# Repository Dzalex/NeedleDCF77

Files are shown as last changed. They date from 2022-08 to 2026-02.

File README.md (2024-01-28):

# NeedleDCF77
## General idea
This project is clock that shows time using three analog meters (with needle) for time and one VFD for date. Main time reference is [DCF77](https://en.wikipedia.org/wiki/DCF77) signal attainable in most of Europe.
### Assembled clock
DSC_9274edit

## Hardware
### Alredy decided
  - Main microcontroller is *STM32L051C8T6*
  - Power supply is implemnted around Analog Device's *LTC3558*
  - DCF77 receive module is *EB6180B1COB77K5A1*
  - [VFD](https://en.wikipedia.org/wiki/Vacuum_fluorescent_display), have old one - itron FG95A
    - Driver PT6312
    - Driver for fillament - LM4871 (alternative for LM9022)
    - Inverting regulator - LT1617
  - Analog meters are:
    - Simpson 60 x 60 mm for Hours
    - 85C1-A for Minutes
    - 91C4 for Seconds
  - Enclosure is wooden box from Alie, 20 x 10 x 6 cm
  - Battery: Panasonic 18650B

## Software
### Hardware design
Corelated to Hardware, Shematic and PCB is designed in *KiCad*.

### IDE and language
For developing purpose we will use *STMCubeIDE*, because of it's flexibility, configurability and support. Also it provide easy access to RTOS option. We use C programing language.

### RTOS
To implemet firmware in this projet we use [FreeRTOS](https://www.freertos.org/). Main reasone to use RTOS instead programing barebone firmware is contribution implementation, so people have less chance to influence other people work. Great chance to learn something about tasks, semafors, mesage queues and other useful features of RTOS! :)

### To decide
  - Planing to use python to implement app for generating time and dates to be able to test.

## Geting stared soon
Coming when some starting point is achived

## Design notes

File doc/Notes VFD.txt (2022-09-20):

- PT6312 je VFD kontroler
	Drajver za filament moze biti LM9022, a to je u stvari spinof LM4871

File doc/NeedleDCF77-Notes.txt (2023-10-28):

//**                     NeedleDCF77 Notes                                  **\\
********************************************************************************

I Sch
    1.  Na USB ulazu, nama se desilo da imamo velike nalete struje kada vežemo
        punjač na kolo koje ima dosta kapacitivnosti ili svičere, koji mogu da 
        povuku dosta struje pre nego što kondenzator dođe skroz sebi. Poslednji
        put smo upotrebili NCP330 (lakše pakovanje za tebe je NCP331) i jako smo
        zadovoljni. Ne znam koliko je realno da se spale pinovi USB-a, ali seti
        se Apple kabla za punjenje i crnih pinova na onom malom konektoru. 
        (Čak je i preporučeno na strani 20 DS-a za LT3558)
    2.  Shield može da se spoji na zemlju ali je dobra praksa da se stavi kolo
        kao na slici 1 i 1.1, kako bi se izolovala DC putanja kroz antenu.            
    3.  Slazem se za 5k1 na CCx pinovima. 
    4.  Napajanje za LTC3558 je preporuceno da ima 1 uF, ti si stavio 10 uF ali 
        elko, ne bi bila loša ideja zameniti to sa keramikom i razmisliti o
        postavljanju nekog ferrite bead-a između USB-a i napajanja (LTC pravi
        lep ripple na napajanju kada radi). Mislim takođe da 100 nF na ulazu ne 
        pomaže ništa :') 
        Mnogo lep blog: https://www.murata.com/en-global/products/emc/emifil/library/knowhow/basic/chapter06-p8
        Posebno su mi interesantni feedthru kondenzatori sa tri pina. 
    5.  Za buck su predložili kaleme od 2.2 uH do 10 uH. Ja bih na tvom mestu
        kupio i 10 uH i nešto između 4.7 uH i 10 uH. Može se desiti da će ripple
        praviti problem. Ne znam koliko će struje vući sve kasnije sa njega ali
        brine me pomalo rad u pulse skip modu kada ćeš imati ripple u kHz a ne 
        MHz. Ostavio bih možda mesta i za ferrite bead između 3V0 i MAS6180, kao 
        i mesta za još par kondenzatora (sa strane U3) ukoliko bude potrebno da 
        se dekapluje šum sa napajanja. Vidim da si ostavio na MCU da se brine o 
        režimu rada napajanja, to je dobro. 
        Verujem da si obratio pažnju na struju zasićenja kalema, ne vidim oznaku
        komponente koju si odabrao. Coilcraft i Taiyo Yuden mi se uvek čine kao 
        bezbedan izbor. 
    6.  Crtao si elektrolite na izlazima LTC3558, na strani 24 DS-a piše da se 
        preporučuju MLCC-ovi, da li je to samo do šeme? 
        Otvori dobro oči na derating kapacitvnosti kod MLCC-ova sa radnim 
        naponom jer može lako da bude >-60%!
    7.  Ispravi me ako grešim, prema formuli sa strane 26 DS-a za LTC3558, 
        napon na izlazu je Vout = 0.8 (1 + Vup/Vdn): 
       
            octave:1> 0.8*(1+(820/300))
            ans = 2.9867 # 3 V rail, tačno je. 
       
            octave:2> 0.8*(1+(300/62))
            ans = 4.6710 # 5 V rail, malo podbacuje? 
            Deluje mi kao da bi trebalo da bude 57k2? 
            
    8.  Note 4 DS-a za MAS6180, na strani 6, mi daje ideju da ga možda napajaš 
        samo sa kondenzatora dok se radi hvatanje signala, on troši uA, ako 
        staviš 100 uF do njega i PMOS iznad, možeš kadkad da ga napuniš i onda
        pustiš da radi neko vreme sa svog napajanja. U tom slučaju bi morao da 
        spustiš napon na PDN pinu, možda i da ga vežeš da bude stalno ON a 
        STM neće imati problem sa malim promenama napona na TIME signalu. 
        Još da se nadaš da LTC ne krene da svičuje na 77 kHz i da ne diže common 
        mode noise preko zemlje :'D
    9.  C25 se puni preko Q1, preko čega se prazni? Možda nije loše ubaciti 
        jednu diodu kod njega.
    10. LT1617 je jako fleksibilan sa kalemima, ne znam da li imaš običan ili -1
        ali čini mi se da ako ti bias ne troši puno struje možeš da odeš do 
        gornjih granica induktivnosti. Otpornici mi deluju ispravno odabrani. 
        Pominju na kraju DS cap od 100 pF u paraleli sa tvojim R16, možda 
        ostaviti makar kao NP? 
    11. Sve oko U6 mi deluje skroz oke :) 
    12. U DS za PT6312 piše da je VIH (in high) min 0.7*VDD tj. 3.5 V, kod tebe
        SPI dolazi od MCU koji radi na 3 V, možda si već probao ovo na kod sebe
        ali meni je red flag. 
    13. Hardverski debounce na tasteru je za pi*** :) (Slika 2, proverena šema)
II PCB
    1.  Nije moralo da bude na dva sloja, ali cenim pošten izazov :D 
    2.  Mislim da je layout ispao super u odnosu na ograničenja. Lično ne volim
        da stavljam kalem sa druge strane ploče zato što će kroz vije stalno da 
        piče impulsi i do pola ampera. Možda bih pojačao trejsove oko dva glavna
        kalema na U1, dodao još vija, pojačao stiching poligona mase gde god je
        moguće jer su dosta isprekidane. 
    3.  Trejs za 3V0 svraća na sve čipove dok stigne do najosetljivijeg U3. Tu 
        će svako da doda po još malo šuma i da napravi mnogo padova napona do
        druge ivice ploče. Mislim da na BOT imaš mesta da po dnu provučeš još
        jedan trejs za 3V0 i da to daš samo U3. (Ako pomeriš 5V0, sl. tačka)
    4.  Izgleda mi kao i da 5V0 možeš uz malo masiranja da provučeš uz gornju 
        ivicu ploče do U4 i ostalih ako SWDIO konektor padne ispod J5. 
        Predlog 3 bi ti ukinuo debeli trejs u BOT sloju za 3V0 koji kreće ispod
        MCU i ostavio mesta za manevar. 
    5.  PWM_Fosc se naslonila uz trejs za DCF77_TIME kao da mu treba još šuma :D
    6.  Mršavo mi deluje ovaj trejs za VBUS, vidim da je 0.3 mm ali samo jedna
        vija, možda dve, biće tu struje kada se puni baterija. 
    6.  Ništa mi više ne upada u oči, 3D izgleda lepo!

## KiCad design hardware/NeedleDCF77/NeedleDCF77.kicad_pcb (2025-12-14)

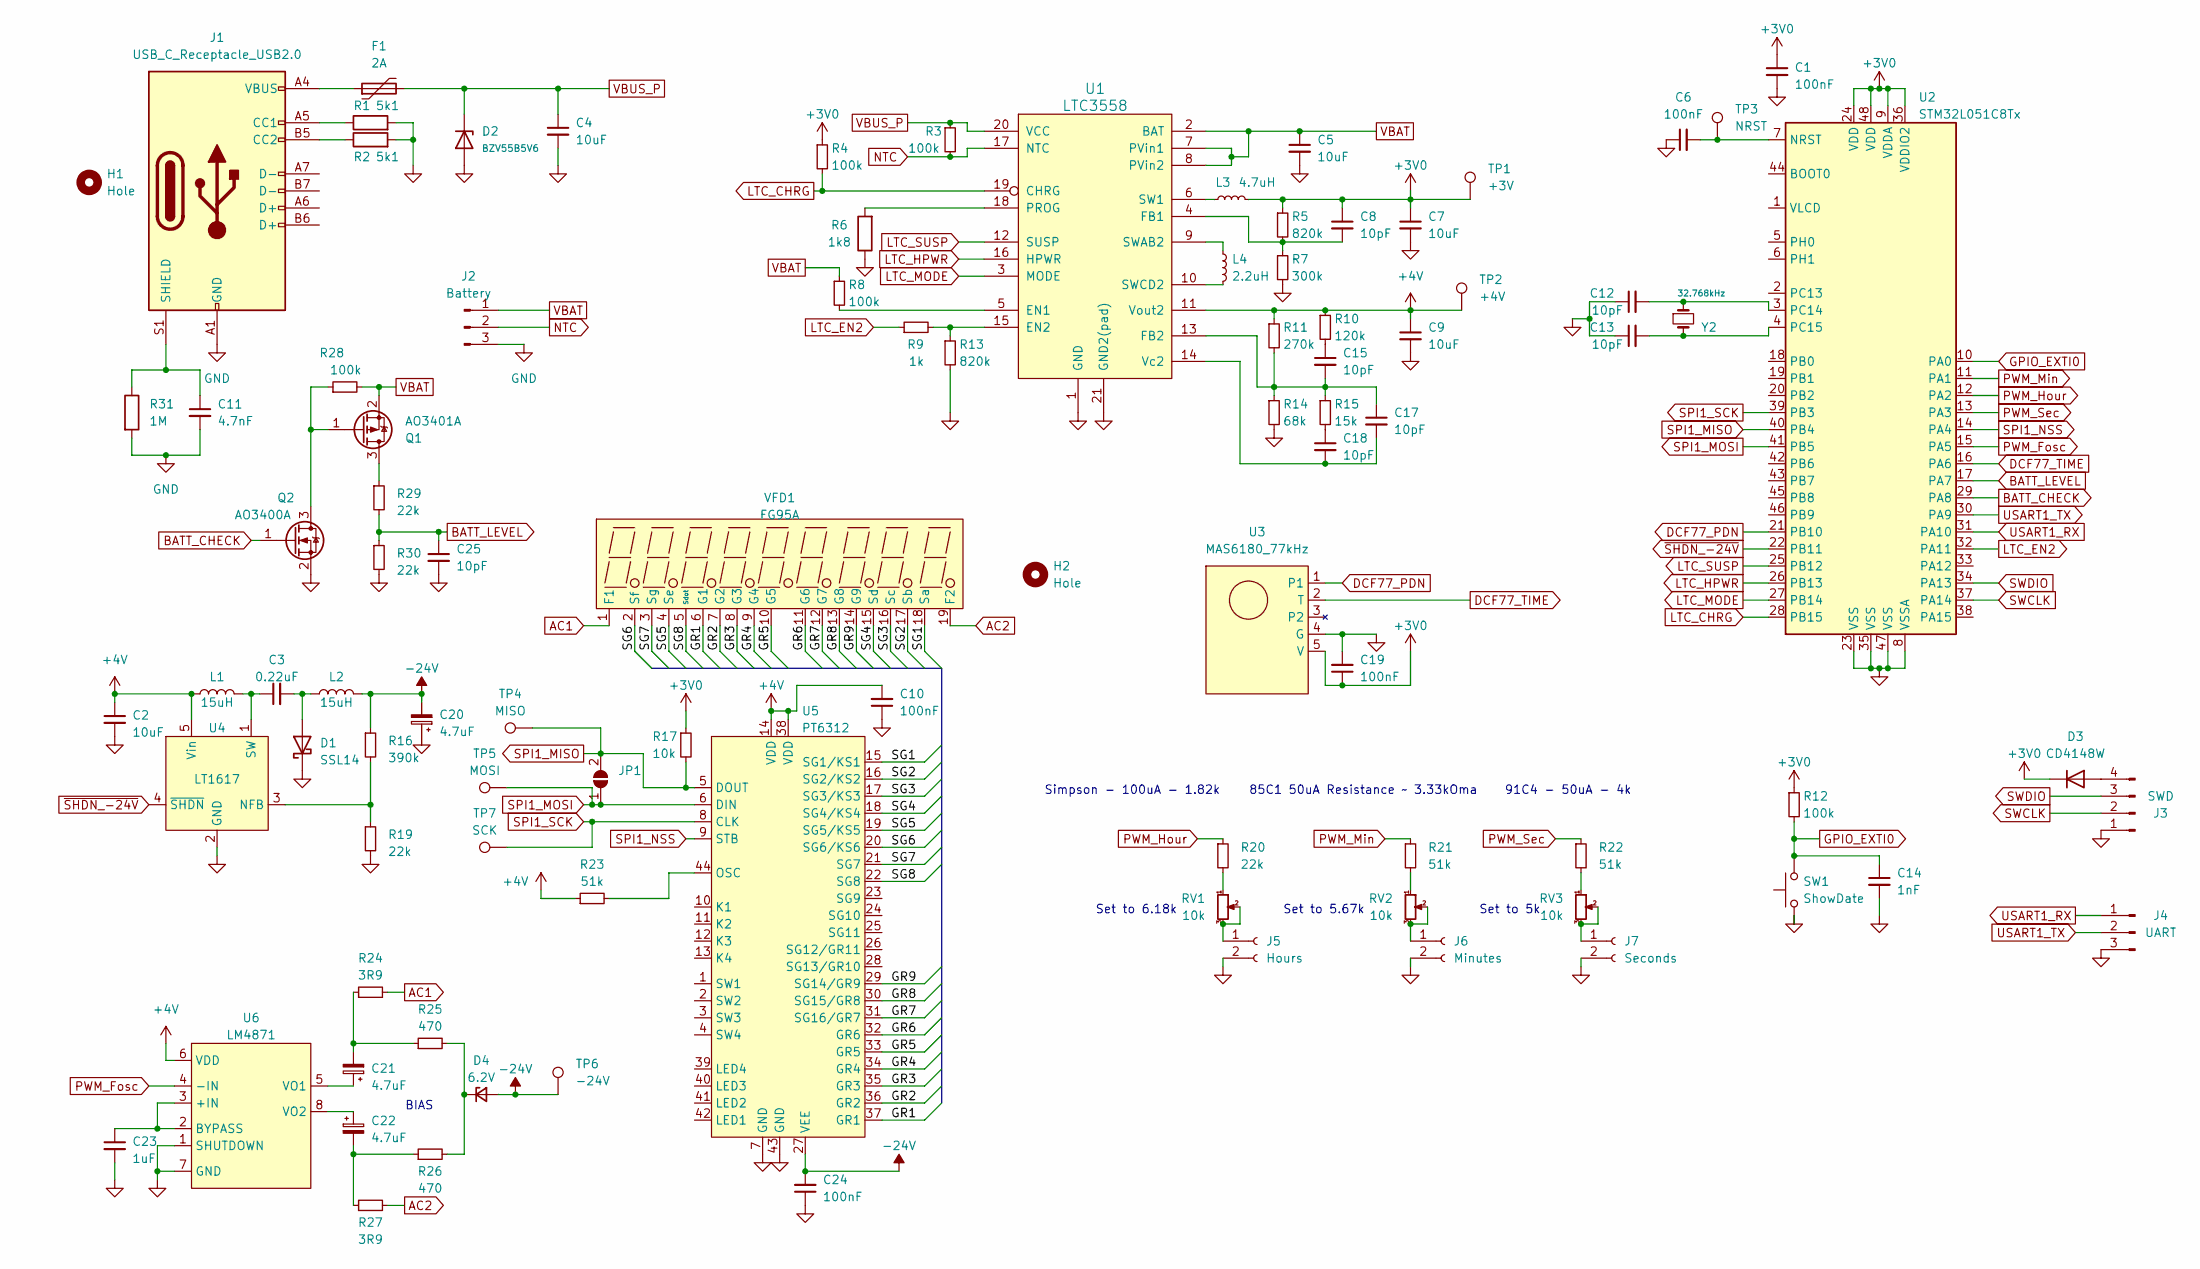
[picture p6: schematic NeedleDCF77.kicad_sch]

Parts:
C1, C6, C10, C19, C24: 100nF; C_0805_2012Metric_Pad1.18x1.45mm_HandSolder
C2, C4, C5, C7, C9: 10uF; C_1206_3216Metric_Pad1.33x1.80mm_HandSolder
C3: 0.22uF; C_1206_3216Metric_Pad1.33x1.80mm_HandSolder
C8, C12, C13, C15, C17, C18, C25: 10pF; C_0805_2012Metric_Pad1.18x1.45mm_HandSolder
C11: 4.7nF; C_1206_3216Metric_Pad1.33x1.80mm_HandSolder
C14: 1nF; C_1206_3216Metric_Pad1.33x1.80mm_HandSolder
C20: 4.7uF; CP_EIA-3528-21_Kemet-B_Pad1.50x2.35mm_HandSolder
C21, C22: 4.7uF; CP_Elec_4x5.7
C23: 1uF; C_0805_2012Metric_Pad1.18x1.45mm_HandSolder
D1: SSL14; D_SMA_Handsoldering
D2: BZV55B5V6; D_MiniMELF
D3: CD4148W; D_0805_2012Metric
D4: 6.2V; D_DO-35_SOD27_P2.54mm_Vertical_AnodeUp
F1: 2A; Fuse_2512_6332Metric_Pad1.52x3.35mm_HandSolder
H1, H2: Hole; MountingHole_3.2mm_M3_DIN965_Pad_TopBottom
J1: USB_C_Receptacle_USB2.0; Molex-2169890001-MFG
J2: Battery; Molex_KK-254_AE-6410-03A_1x03_P2.54mm_Vertical
J3: SWD; PinHeader_1x04_P2.54mm_Vertical
J4: UART; PinHeader_1x03_P2.54mm_Vertical
J5: Hours; Molex_KK-254_AE-6410-02A_1x02_P2.54mm_Vertical
J6: Minutes; Molex_KK-254_AE-6410-02A_1x02_P2.54mm_Vertical
J7: Seconds; Molex_KK-254_AE-6410-02A_1x02_P2.54mm_Vertical
JP1: SolderJumper-2_P1.3mm_Open_TrianglePad1.0x1.5mm
L1, L2: 15uH; L_12x12mm_H8mm
L3: 4.7uH; L_Ferrocore_DLG-0504
L4: 2.2uH; L_Ferrocore_DLG-0504
Q1: AO3401A; SOT-23
Q2: AO3400A; SOT-23
R1, R2: 5k1; R_0805_2012Metric_Pad1.20x1.40mm_HandSolder
R3, R4, R8, R12, R28: 100k; R_0805_2012Metric_Pad1.20x1.40mm_HandSolder
R5, R13: 820k; R_0805_2012Metric_Pad1.20x1.40mm_HandSolder
R6: 1k8; R_0805_2012Metric_Pad1.20x1.40mm_HandSolder
R7: 300k; R_0805_2012Metric_Pad1.20x1.40mm_HandSolder
R9: 1k; R_0805_2012Metric_Pad1.20x1.40mm_HandSolder
R10: 120k; R_1206_3216Metric_Pad1.30x1.75mm_HandSolder
R11: 270k; R_0805_2012Metric_Pad1.20x1.40mm_HandSolder
R14: 68k; R_Axial_DIN0207_L6.3mm_D2.5mm_P2.54mm_Vertical
R15: 15k; R_0805_2012Metric_Pad1.20x1.40mm_HandSolder
R16: 390k; R_0805_2012Metric_Pad1.20x1.40mm_HandSolder
R17: 10k; R_0805_2012Metric_Pad1.20x1.40mm_HandSolder
R19, R20, R29, R30: 22k; R_0805_2012Metric_Pad1.20x1.40mm_HandSolder
R21, R22, R23: 51k; R_0603_1608Metric_Pad0.98x0.95mm_HandSolder
R24, R27: 3R9; R_1206_3216Metric_Pad1.30x1.75mm_HandSolder
R25, R26: 470; R_0805_2012Metric_Pad1.20x1.40mm_HandSolder
R31: 1M; R_0805_2012Metric_Pad1.20x1.40mm_HandSolder
RV1, RV2, RV3: 10k; Potentiometer_Bourns_3296Y_Vertical
SW1: ShowDate; Molex_KK-254_AE-6410-02A_1x02_P2.54mm_Vertical
TP1: +3V; TestPoint_Pad_1.5x1.5mm
TP2: +4V; TestPoint_Pad_1.5x1.5mm
TP3: NRST; TestPoint_Pad_1.5x1.5mm
TP4: MISO; TestPoint_Pad_1.5x1.5mm
TP5: MOSI; TestPoint_Pad_1.5x1.5mm
TP6: -24V; TestPoint_Pad_1.5x1.5mm
TP7: SCK; TestPoint_Pad_1.5x1.5mm
U1: LTC3558; QFN-20-1EP_3x3mm_P0.4mm_EP1.65x1.65mm
U2: STM32L051C8Tx; LQFP-48_7x7mm_P0.5mm
U3: MAS6180_77kHz; MAS6180_module
U4: LT1617; SOT-23-5_HandSoldering
U5: PT6312; LQFP-44_10x10mm_P0.8mm
U6: LM4871; SOIC-8_3.9x4.9mm_P1.27mm
VFD1: FG95A
Y2: 32.768kHz; Crystal_C38-LF_D3.0mm_L8.0mm_Horizontal

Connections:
+3V0: C1.1, C7.1, C8.1, C19.1, D3.1 (K), L3.2, R4.1, R5.1, R12.1, R17.1, TP1.1, U2.9 (VDDA), U2.24 (VDD), U2.36 (VDDIO2), U2.48 (VDD), U3.5 (V)
+4V: C2.1, C9.1, C10.2, L1.1, R10.1, R11.1, R23.1, TP2.1, U1.11 (Vout2), U4.5 (Vin), U5.14 (VDD), U5.38 (VDD), U6.6 (VDD)
-24V: C20.2, C24.2, D4.2 (A), L2.2, R16.1, TP6.1, U5.27 (VEE)
/GR1: U5.37 (GR1), VFD1.6 (G1)
/GR2: U5.36 (GR2), VFD1.7 (G2)
/GR3: U5.35 (GR3), VFD1.8 (G3)
/GR4: U5.34 (GR4), VFD1.9 (G4)
/GR5: U5.33 (GR5), VFD1.10 (G5)
/GR6: U5.32 (GR6), VFD1.11 (G6)
/GR7: U5.31 (SG16/GR7), VFD1.12 (G7)
/GR8: U5.30 (SG15/GR8), VFD1.13 (G8)
/GR9: U5.29 (SG14/GR9), VFD1.14 (G9)
/SG1: U5.15 (SG1/KS1), VFD1.18 (Sa)
/SG2: U5.16 (SG2/KS2), VFD1.17 (Sb)
/SG3: U5.17 (SG3/KS3), VFD1.16 (Sc)
/SG4: U5.18 (SG4/KS4), VFD1.15 (Sd)
/SG5: U5.19 (SG5/KS5), VFD1.4 (Se)
/SG6: U5.20 (SG6/KS6), VFD1.2 (Sf)
/SG7: U5.21 (SG7), VFD1.3 (Sg)
/SG8: U5.22 (SG8), VFD1.5 (Sdot)
AC1: R24.2, VFD1.1 (F1)
AC2: R27.2, VFD1.19 (F2)
BATT_CHECK: Q2.1 (G), U2.29 (PA8)
BATT_LEVEL: C25.1, R29.2, R30.1, U2.17 (PA7)
DCF77_PDN: U2.21 (PB10), U3.1
DCF77_TIME: U2.16 (PA6), U3.2 (T)
GND: C1.2, C2.2, C4.2, C5.2, C6.1, C7.2, C9.2, C10.1, C11.2, C12.1, C13.1, C14.2, C19.2, C20.1, C23.2, C24.1, C25.2, D1.1 (K), D2.2 (A), J1.A1 (GND), J1.A12 (GND), J1.B1 (GND), J1.B12 (GND), J2.3, J3.1, J4.3, J5.2, J6.2, J7.2, Q2.2 (S), R1.2, R2.2, R6.1, R7.2, R13.2, R14.2, R19.2, R30.2, R31.2, SW1.1, U1.1 (GND), U1.21 (GND2(pad)), U2.8 (VSSA), U2.23 (VSS), U2.35 (VSS), U2.47 (VSS), U3.4 (G), U4.2 (GND), U5.7 (GND), U5.43 (GND), U6.1 (SHUTDOWN), U6.7 (GND)
GPIO_EXTI0: C14.1, R12.2, SW1.2, U2.10 (PA0)
LTC_CHRG: R4.2, U1.19 (CHRG), U2.28 (PB15)
LTC_EN2: R9.1, U2.32 (PA11)
LTC_HPWR: U1.16 (HPWR), U2.26 (PB13)
LTC_MODE: U1.3 (MODE), U2.27 (PB14)
LTC_SUSP: U1.12 (SUSP), U2.25 (PB12)
NTC: J2.2, R3.2, U1.17 (NTC)
unnamed: C15.1, R10.2
unnamed: C18.1, R15.2
unnamed: C21.2, R24.1, R25.1
unnamed: C22.2, R26.1, R27.1
unnamed: C3.2, D1.2 (A), L2.1
unnamed: D3.2 (A), J3.4
unnamed: D4.1 (K), R25.2, R26.2
unnamed: F1.1, J1.A4 (VBUS), J1.A9 (VBUS), J1.B4 (VBUS), J1.B9 (VBUS)
unnamed: J1.A5 (CC1), R1.1
unnamed: J1.B5 (CC2), R2.1
unnamed: C11.1, J1.S1 (SHIELD), R31.1
unnamed: J5.1, RV1.2, RV1.3
unnamed: J6.1, RV2.2, RV2.3
unnamed: J7.1, RV3.2, RV3.3
unnamed: Q1.3 (D), R29.1
unnamed: Q1.1 (G), Q2.3 (D), R28.1
unnamed: R20.2, RV1.1
unnamed: R21.2, RV2.1
unnamed: R22.2, RV3.1
unnamed: R8.2, U1.5 (EN1)
unnamed: R9.2, R13.1, U1.15 (EN2)
unnamed: C8.2, R5.2, R7.1, U1.4 (FB1)
unnamed: C15.2, C17.1, R11.2, R14.1, R15.1, U1.13 (FB2)
unnamed: R6.2, U1.18 (PROG)
unnamed: L3.1, U1.6 (SW1)
unnamed: L4.1, U1.9 (SWAB2)
unnamed: L4.2, U1.10 (SWCD2)
unnamed: C17.2, C18.2, U1.14 (Vc2)
unnamed: C6.2, TP3.1, U2.7 (NRST)
unnamed: C12.2, U2.3 (PC14), Y2.1
unnamed: C13.2, U2.4 (PC15), Y2.2
unnamed: R16.2, R19.1, U4.3 (NFB)
unnamed: C3.1, L1.2, U4.1 (SW)
unnamed: R23.2, U5.44 (OSC)
unnamed: C23.1, U6.2 (BYPASS), U6.3 (+IN)
unnamed: C21.1, U6.5 (VO1)
unnamed: C22.1, U6.8 (VO2)
PWM_Fosc: U2.15 (PA5), U6.4 (-IN)
PWM_Hour: R20.1, U2.12 (PA2)
PWM_Min: R21.1, U2.11 (PA1)
PWM_Sec: R22.1, U2.13 (PA3)
SPI1_MISO: JP1.2 (B), R17.2, TP4.1, U2.40 (PB4), U5.5 (DOUT)
SPI1_MOSI: JP1.1 (A), TP5.1, U2.41 (PB5), U5.6 (DIN)
SPI1_NSS: U2.14 (PA4), U5.9 (STB)
SPI1_SCK: TP7.1, U2.39 (PB3), U5.8 (CLK)
SWCLK: J3.2, U2.37 (PA14)
SWDIO: J3.3, U2.34 (PA13)
USART1_RX: J4.1, U2.31 (PA10)
USART1_TX: J4.2, U2.30 (PA9)
VBAT: C5.1, J2.1, Q1.2 (S), R8.1, R28.2, U1.2 (BAT), U1.7 (PVin1), U1.8 (PVin2)
VBUS_P: C4.1, D2.1 (K), F1.2, R3.1, U1.20 (VCC)
~SHDN_-24V: U2.22 (PB11), U4.4 (~SHDN)

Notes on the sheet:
91C4 - 50uA - 4k
Set to 5.67k
Set to 5k
Set to 6.18k
Simpson - 100uA - 1.82k
85C1 50uA Resistance ~ 3.33kOma
BIAS

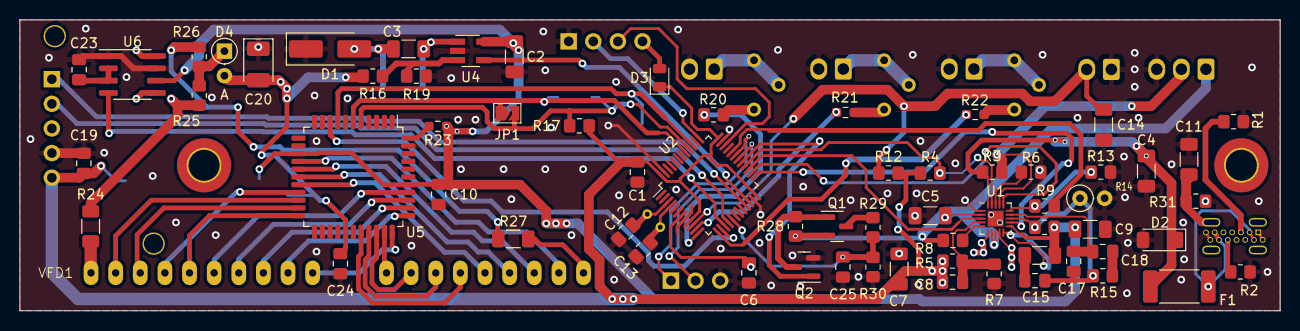
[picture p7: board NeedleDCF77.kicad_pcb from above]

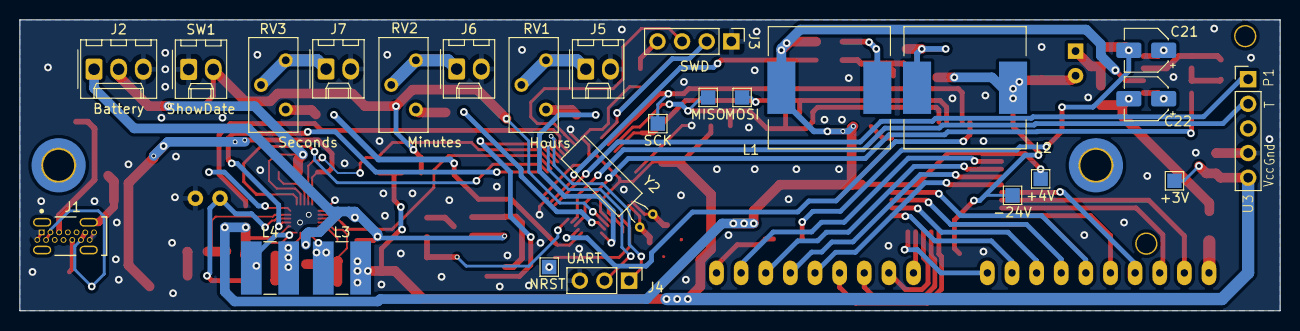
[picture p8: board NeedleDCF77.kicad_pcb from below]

Board: 2 copper layers, 130.0 x 30.0 mm, 94 parts (26 on the bottom side), 86 nets.

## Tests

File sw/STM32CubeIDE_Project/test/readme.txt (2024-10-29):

Build and run with Meson
---
Run `meson setup build` to create the build directory, and then `meson test -C build` to build and run the tests.

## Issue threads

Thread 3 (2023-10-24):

Footprint for USB C connector is wrong

Dzalex, 2023-10-24:
## Description

On the PCB connector pads are with wrong dimensions and also are not THD, but are plain vias.

### Issue found after production, in version V1.0_PCB_production
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

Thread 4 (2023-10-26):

R14 - 68k wrong package

Dzalex, 2023-10-26:
## Decription

There was some changes regarding resistor value but package remain THD. Still usable, fix package

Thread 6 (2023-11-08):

Add fuse to battery

Dzalex, 2023-11-08:
Use same 2A fuse, as for USB, to protect battery or board from damage to battery circuit.

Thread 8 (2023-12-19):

Rosc value is wrong and specific to particular PT6312

Dzalex, 2023-12-19:
Value of oscillating resistor is wrong for 4V.
@3V it states that 30k is used, but at that frequency there is difficulty to oscillate.
Resistor used is ~23kOhm.

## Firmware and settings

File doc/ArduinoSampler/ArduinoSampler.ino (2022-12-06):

int val = 0;

// the setup function runs once when you press reset or power the board
void setup() {
  Serial.begin(115200);
  // initialize digital pin LED_BUILTIN as an output.
  pinMode(LED_BUILTIN, OUTPUT);
  pinMode(19, INPUT);
}

// the loop function runs over and over again forever
void loop() {
  val = digitalRead(19);
  Serial.print(val);
  Serial.print(", ");
  digitalWrite(LED_BUILTIN, val);
  delay(10);             
}

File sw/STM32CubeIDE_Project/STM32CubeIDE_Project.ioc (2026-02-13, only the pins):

Mcu.UserName=STM32L051C8Tx
PA0.Signal=GPXTI0
PA1.GPIO_Label=PWM_Min
PA1.Signal=S_TIM2_CH2
PA11.GPIO_Label=LTC_EN2
PA11.Signal=GPIO_Output
PA13.Signal=SYS_SWDIO
PA14.Signal=SYS_SWCLK
PA2.GPIO_Label=PWM_Hour
PA2.Signal=S_TIM2_CH3
PA3.GPIO_Label=PWM_Sec
PA3.Signal=S_TIM2_CH4
PA4.GPIO_Label=VFD_STB
PA4.Signal=GPIO_Output
PA5.GPIO_Label=PWM_FOSC
PA5.Signal=S_TIM2_CH1
PA6.Signal=S_TIM22_CH1
PA7.GPIO_Label=BATT_LEVEL
PA7.Signal=ADC_IN7
PA8.GPIO_Label=BATT_CHECK
PA8.Signal=GPIO_Output
PB10.GPIO_Label=DCF77_PDN
PB10.Signal=GPIO_Output
PB11.GPIO_Label=SHDN_24V
PB11.Signal=GPIO_Output
PB12.GPIO_Label=LTC_SUSP
PB12.Signal=GPIO_Output
PB13.GPIO_Label=LTC_HPWR
PB13.Signal=GPIO_Output
PB14.GPIO_Label=LTC_MODE
PB14.Signal=GPIO_Output
PB15.GPIO_Label=LTC_CHRG
PB15.Signal=GPIO_Input
PB3.Signal=SPI1_SCK
PB4.Signal=SPI1_MISO
PB5.Signal=SPI1_MOSI
PC14-OSC32_IN.Signal=RCC_OSC32_IN
PC15-OSC32_OUT.Signal=RCC_OSC32_OUT

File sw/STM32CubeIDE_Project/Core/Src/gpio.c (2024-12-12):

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

/* Includes ------------------------------------------------------------------*/
#include "gpio.h"

/*----------------------------------------------------------------------------*/
/* Configure GPIO                                                             */
/*----------------------------------------------------------------------------*/
/** Configure pins as
        * Analog
        * Input
        * Output
        * EVENT_OUT
        * EXTI
        * Free pins are configured automatically as Analog (this feature is enabled through
        * the Code Generation settings)
*/
void MX_GPIO_Init(void)
{

  GPIO_InitTypeDef GPIO_InitStruct = {0};

  /* GPIO Ports Clock Enable */
  __HAL_RCC_GPIOC_CLK_ENABLE();
  __HAL_RCC_GPIOH_CLK_ENABLE();
  __HAL_RCC_GPIOA_CLK_ENABLE();
  __HAL_RCC_GPIOB_CLK_ENABLE();

  /*Configure GPIO pin Output Level */
  HAL_GPIO_WritePin(VFD_STB_GPIO_Port, VFD_STB_Pin, GPIO_PIN_SET);

  /*Configure GPIO pin Output Level */
  HAL_GPIO_WritePin(DCF77_PDN_GPIO_Port, DCF77_PDN_Pin, GPIO_PIN_SET);

  /*Configure GPIO pin Output Level */
  HAL_GPIO_WritePin(GPIOB, SHDN_24V_Pin|LTC_SUSP_Pin|LTC_HPWR_Pin|LTC_MODE_Pin, GPIO_PIN_RESET);

  /*Configure GPIO pin Output Level */
  HAL_GPIO_WritePin(GPIOA, BATT_CHECK_Pin|LTC_EN2_Pin, GPIO_PIN_RESET);

  /*Configure GPIO pin : PC13 */
  GPIO_InitStruct.Pin = GPIO_PIN_13;
  GPIO_InitStruct.Mode = GPIO_MODE_ANALOG;
  GPIO_InitStruct.Pull = GPIO_NOPULL;
  HAL_GPIO_Init(GPIOC, &GPIO_InitStruct);

  /*Configure GPIO pins : PH0 PH1 */
  GPIO_InitStruct.Pin = GPIO_PIN_0|GPIO_PIN_1;
  GPIO_InitStruct.Mode = GPIO_MODE_ANALOG;
  GPIO_InitStruct.Pull = GPIO_NOPULL;
  HAL_GPIO_Init(GPIOH, &GPIO_InitStruct);

  /*Configure GPIO pin : PA0 */
  GPIO_InitStruct.Pin = GPIO_PIN_0;
  GPIO_InitStruct.Mode = GPIO_MODE_IT_FALLING;
  GPIO_InitStruct.Pull = GPIO_NOPULL;
  HAL_GPIO_Init(GPIOA, &GPIO_InitStruct);

  /*Configure GPIO pins : VFD_STB_Pin BATT_CHECK_Pin LTC_EN2_Pin */
  GPIO_InitStruct.Pin = VFD_STB_Pin|BATT_CHECK_Pin|LTC_EN2_Pin;
  GPIO_InitStruct.Mode = GPIO_MODE_OUTPUT_PP;
  GPIO_InitStruct.Pull = GPIO_NOPULL;
  GPIO_InitStruct.Speed = GPIO_SPEED_FREQ_LOW;
  HAL_GPIO_Init(GPIOA, &GPIO_InitStruct);

  /*Configure GPIO pins : PB0 PB1 PB2 PB6
                           PB7 PB8 PB9 */
  GPIO_InitStruct.Pin = GPIO_PIN_0|GPIO_PIN_1|GPIO_PIN_2|GPIO_PIN_6
                          |GPIO_PIN_7|GPIO_PIN_8|GPIO_PIN_9;
  GPIO_InitStruct.Mode = GPIO_MODE_ANALOG;
  GPIO_InitStruct.Pull = GPIO_NOPULL;
  HAL_GPIO_Init(GPIOB, &GPIO_InitStruct);

  /*Configure GPIO pins : DCF77_PDN_Pin SHDN_24V_Pin LTC_SUSP_Pin LTC_HPWR_Pin
                           LTC_MODE_Pin */
  GPIO_InitStruct.Pin = DCF77_PDN_Pin|SHDN_24V_Pin|LTC_SUSP_Pin|LTC_HPWR_Pin
                          |LTC_MODE_Pin;
  GPIO_InitStruct.Mode = GPIO_MODE_OUTPUT_PP;
  GPIO_InitStruct.Pull = GPIO_NOPULL;
  GPIO_InitStruct.Speed = GPIO_SPEED_FREQ_LOW;
  HAL_GPIO_Init(GPIOB, &GPIO_InitStruct);

  /*Configure GPIO pin : LTC_CHRG_Pin */
  GPIO_InitStruct.Pin = LTC_CHRG_Pin;
  GPIO_InitStruct.Mode = GPIO_MODE_INPUT;
  GPIO_InitStruct.Pull = GPIO_PULLUP;
  HAL_GPIO_Init(LTC_CHRG_GPIO_Port, &GPIO_InitStruct);

  /*Configure GPIO pins : PA9 PA10 PA12 PA15 */
  GPIO_InitStruct.Pin = GPIO_PIN_9|GPIO_PIN_10|GPIO_PIN_12|GPIO_PIN_15;
  GPIO_InitStruct.Mode = GPIO_MODE_ANALOG;
  GPIO_InitStruct.Pull = GPIO_NOPULL;
  HAL_GPIO_Init(GPIOA, &GPIO_InitStruct);

  /* EXTI interrupt init*/
  HAL_NVIC_SetPriority(EXTI0_1_IRQn, 3, 0);
  HAL_NVIC_EnableIRQ(EXTI0_1_IRQn);

}



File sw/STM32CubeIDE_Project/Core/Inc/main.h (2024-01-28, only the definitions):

#define RTC_CAL_CALM_VALUE 93
#define PWM_Min_Pin GPIO_PIN_1
#define PWM_Min_GPIO_Port GPIOA
#define PWM_Hour_Pin GPIO_PIN_2
#define PWM_Hour_GPIO_Port GPIOA
#define PWM_Sec_Pin GPIO_PIN_3
#define PWM_Sec_GPIO_Port GPIOA
#define VFD_STB_Pin GPIO_PIN_4
#define VFD_STB_GPIO_Port GPIOA
#define PWM_FOSC_Pin GPIO_PIN_5
#define PWM_FOSC_GPIO_Port GPIOA
#define BATT_LEVEL_Pin GPIO_PIN_7
#define BATT_LEVEL_GPIO_Port GPIOA
#define DCF77_PDN_Pin GPIO_PIN_10
#define DCF77_PDN_GPIO_Port GPIOB
#define SHDN_24V_Pin GPIO_PIN_11
#define SHDN_24V_GPIO_Port GPIOB
#define LTC_SUSP_Pin GPIO_PIN_12
#define LTC_SUSP_GPIO_Port GPIOB
#define LTC_HPWR_Pin GPIO_PIN_13
#define LTC_HPWR_GPIO_Port GPIOB
#define LTC_MODE_Pin GPIO_PIN_14
#define LTC_MODE_GPIO_Port GPIOB
#define LTC_CHRG_Pin GPIO_PIN_15
#define LTC_CHRG_GPIO_Port GPIOB
#define BATT_CHECK_Pin GPIO_PIN_8
#define BATT_CHECK_GPIO_Port GPIOA
#define LTC_EN2_Pin GPIO_PIN_11
#define LTC_EN2_GPIO_Port GPIOA

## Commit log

2022-03-27 Create hardware project (KiCad project)
    [NeedleDCF77.kicad_pcb, NeedleDCF77.kicad_sch]
2022-03-27 Add .zip ignore for KiCad
2022-03-27 First schematic save
    [NeedleDCF77.kicad_sch]
2022-03-28 Create footprint for MINI-M4
2022-03-28 Add MINI-M4 to schematic
    [NeedleDCF77.kicad_sch]
2022-03-28 Init PCB
    [NeedleDCF77.kicad_pcb, NeedleDCF77.kicad_sch]
2022-04-01 Add library with LTC3558 and add it to schematic
    [NeedleDCF77.kicad_sch]
2022-04-16 Edit LTC3558 dimensions
    [NeedleDCF77.kicad_sch]
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2022-08-28 Create STM32Cube project with freeRtos and CMSISv2 API
    Check if it is possible to not use CMSIS...
2022-09-08 Change main MCU to STM32L051
    [NeedleDCF77.kicad_sch]
2022-09-19 Implementation of 3V
    [NeedleDCF77.kicad_pcb, NeedleDCF77.kicad_sch]
2022-09-20 More work on PS
    [NeedleDCF77.kicad_sch]
2022-09-20 Create empty project for STM32L051C8T6
2022-09-20 Start configuring MCU
    [NeedleDCF77.kicad_sch]
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2022-11-26 Initial analysis with matching filter. Not working.
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2022-12-06 Unknown changes in schematic - forget to commit
    [NeedleDCF77.kicad_sch]
2022-12-06 Create symbol for PT6312 and add it to schematic
    [NeedleDCF77.kicad_sch]
2022-12-06 Update page setup
    [NeedleDCF77.kicad_sch]
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2022-12-09 Update schematic IC symbol background
    [NeedleDCF77.kicad_sch]
2023-02-19 Add LM4871/LM9022
    [NeedleDCF77.kicad_sch]
2023-02-19 Move to KiCad 7.0
    [NeedleDCF77.kicad_pcb, NeedleDCF77.kicad_sch]
2023-03-10 Chose correct pins for PWM
    [NeedleDCF77.kicad_sch]
2023-03-10 Chose correct pins for SPI1
    [NeedleDCF77.kicad_sch]
2023-03-10 Chose correct pins for UART1
    [NeedleDCF77.kicad_sch]
2023-03-10 Update pins corrections in CubeMX
    [STM32CubeIDE_Project.ioc, gpio.c, main.h]
2023-03-20 Add ground to PT6312
    [NeedleDCF77.kicad_sch]
2023-04-14 Create Symbol for LM4871 and add it to schematic
    [NeedleDCF77.kicad_sch]
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2023-05-01 Create -24V power supply
    [NeedleDCF77.kicad_sch]
2023-05-01 Implement VFD circuit
    [NeedleDCF77.kicad_sch]
2023-05-01 Implement 5V for VFD circuitry
    [NeedleDCF77.kicad_sch]
2023-07-03 Change positions of schematic components
    [NeedleDCF77.kicad_sch]
2023-07-03 Add solder jumper between Dout and Din for PT6312
    [NeedleDCF77.kicad_sch]
2023-07-03 Change WKUP to EXTI0, so we are unable to get out of LowPower modes, no STOP
    [NeedleDCF77.kicad_sch]
2023-07-03 Add debug interfaces
    [NeedleDCF77.kicad_sch]
2023-07-03 Connect LTC3558 logic to MCU
    [NeedleDCF77.kicad_sch]
2023-07-03 Connect LT1617 shutdown to MCU
    [NeedleDCF77.kicad_sch]
2023-07-03 Name Fosc signal correctly
    [NeedleDCF77.kicad_sch]
2023-07-05 Add DCF77 receiver module
    [NeedleDCF77.kicad_sch]
2023-07-07 Connect DCF77 module to MCU
    [NeedleDCF77.kicad_sch]
2023-07-07 Add push button for date show
    [NeedleDCF77.kicad_sch]
2023-07-08 Add footprints and supplier codes - AMEND TO THIS
    [NeedleDCF77.kicad_sch]
2023-07-08 Add new symbol to 32khz crystal so we can access ground
    [NeedleDCF77.kicad_sch]
2023-07-08 Import changes to PCB
    [NeedleDCF77.kicad_pcb]
2023-08-06 Add battery measurement circuit and generate ADC code
    [NeedleDCF77.kicad_pcb, NeedleDCF77.kicad_sch]
2023-08-21 Bulk work - working on layout
    [NeedleDCF77.kicad_pcb, NeedleDCF77.kicad_sch]
2023-08-21 Use HSI instead of HSE
    [NeedleDCF77.kicad_pcb, NeedleDCF77.kicad_sch]
2023-08-30 Add new USB C connector, flag type, Molex
2023-08-30 Initial version of PCB placement and routing
    [NeedleDCF77.kicad_pcb, NeedleDCF77.kicad_sch]
2023-08-30 Add PinSocket to VFD
    [NeedleDCF77.kicad_pcb]
2023-09-02 Add test points to schematic and board
    [NeedleDCF77.kicad_pcb, NeedleDCF77.kicad_sch]
2023-09-02 Minor improvements regarding coupling and silkscreen
    [NeedleDCF77.kicad_pcb, NeedleDCF77.kicad_sch]
2023-09-24 Fix points from Nikola's review + add logo
    [NeedleDCF77.kicad_pcb, NeedleDCF77.kicad_sch]
2023-09-28 Final improvements
    [NeedleDCF77.kicad_pcb, NeedleDCF77.kicad_sch]
2023-09-28 Fix pin naming
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2023-11-08 Fix needle Set functions
    [needle.c]
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2023-11-09 Save Debug configuration for OpecOCD
    [STM32CubeIDE_Project Debug.cfg]
2023-11-19 Enable RTC WakeUp option and enable interrupt for wake up
2023-11-19 Fix needle position for 12AM/PM
    [needle.c]
2023-11-20 Implement first interrupt/event based clock with task interface
2023-11-22 Use burst mode as main power mode - 1mA
2023-11-22 Use MSI clock @ 4194kHz as main clock; this disables PLL and HSI which are power hungry - > 1mA
2023-11-22 Set internal regulator to voltage range 3 - 0.3mA
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2023-11-23 Set all free pins as analog - optimize power consumption
2024-01-01 Implement VFD library and provide function to show Date (#9)
    * Set SPI for communication with PT6312
    * Define VFD commands 1 and 2
    * Add Command 3 and Command 4 and signature of initialisation function
    * Add first font with numbers
    * Add Pulse value for PWM channel 1 - Fosc for VFD
    * Implement command function for VFD
    * Implement VFD clear
    * Implement VFD initialization function
    * Speed up PWM frequency so we can heat up
    * Lower the speed of VFD transmission
    * Prepare for testing
    * Fix font
    * Use GPIO as Strobe instead of NSS option of SPI
    * Fix VFD_Command, Implement strobe functions and fix clear
    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
    [STM32CubeIDE_Project.ioc, gpio.c, interface.c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]
2024-01-04 Support button to display date and start synch (#10)
    * Create new timer for periodic checking of button - if it is active multiple times it is being held
    * Detect falling edge of button signal
    * Enable showing of date on button press
    * Only INTERFACE_SECOND_FLAG was able to Unblock a task, all flags can unblock on wait
    * Refactor naming for OS timer
    * Add timer to turn of VFD
    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
2024-01-04 Implement PrintPositiveNumber so we can show number on VFD
2024-01-05 Implement battery voltage get function with helper functions to enable its readout
2024-01-23 Implemet time pulse sampling for DCF77 (#11)
    * Use TIM22 for DCF77 time signal input capture measuring
    Prescaler to get 1ms resolution
    Capture on both edges
    Filter noise with 5
    * Enable TIM22 global interrupt
    * Add dcf.h and enabling of receiver
    * Use TIM22 as PWM input on IC1 pin, IC2 register secondary
    * Refactor dcf77 with addition of timer start and stop functions
    * Add message queue for DCF77 samples received by tim22 ISR
    * Add ISR callback function for DCF77 timer input capture
    * Example of how to use DCF77 Message queue of time samples
    [STM32CubeIDE_Project.ioc, dcf77.c, gpio.c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]
2024-01-28 Add calibration value to RTC using LL driver
    Calculated CALM value using https://gist.github.com/esynr3z/8284f6dc10feab1e00609f26e42b974c
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2024-10-29 Initial implementation and usage of DCF77 signal decoding (#12)
    * Add initial constants
    * Add dcf77 buffer
    * Check what pulse we received
    * Use union for DCF77 buffer
    * Implement function that will fill buffer on specific location
    * Add timeout constant
    * Remove global struct
    * Begin GetTimeAndDate implementation in DCF77
    * Export data diagnostic function so we can test and use them
    * Extract decoding functionality to improve testing and modularity
    * Configure unity test framework with meson build
    * Test IsFirstBitOne and repair issues found by test
    * Test Encoding bit check function and Parity functions
    * Finish implementation of CheckBuffer integrity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
    [STM32CubeIDE_Project.ioc, dcf77.c, interface.c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]
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2024-12-12 Update KiCad project
    [NeedleDCF77.kicad_sch]
2025-12-14 Update KiCad version of project
    [NeedleDCF77.kicad_pcb, NeedleDCF77.kicad_sch]
2026-02-13 Enable TICKLESS_IDLE and setup programing in low power mode
    [STM32CubeIDE_Project Debug.cfg]
2026-07-19 Minor improvements
    dcf77Decoding.c - check current bit position
    missing void-s
    Reset DCF77 buffer before first iteration in sync
    Check result of RTC time and date setting

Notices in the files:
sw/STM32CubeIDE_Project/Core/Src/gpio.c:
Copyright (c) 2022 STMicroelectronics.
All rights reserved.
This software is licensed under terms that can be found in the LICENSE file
